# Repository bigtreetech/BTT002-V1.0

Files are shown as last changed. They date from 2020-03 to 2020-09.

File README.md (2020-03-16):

### Note
* The firmware of this motherboard is default Marlin2.0；
* Since the prusa machine is not equipped with endstop switch, to use the endstop switch function, either TMC2130 or TMC2209 must be used.According to the test results, using the TMC2209 driver is more cost-effective. Therefore, it is recommended that the customer use TMC2209 driver；
* If you want to use drivers other than TMC2209 and TMC2130, you need to install endstop switch on the machine；
* Because the board uses a plug drive, the overall height is higher than the original machine housing. According to the motherboard, our company makes a 3D model to adapte the shell. So the customer can printed out the shell and install on the machine for use;
* The firmware of the motherboard is updated by SD card. The client can put the compiled. bin file into the SD card of LCD2004 screen, then repower to update the firmware.
* When using Marlin firmware, you can use the new processing capabilities such as RGB light function, WIFI printing function, TFT touch screen and dual-mode touch  screen.

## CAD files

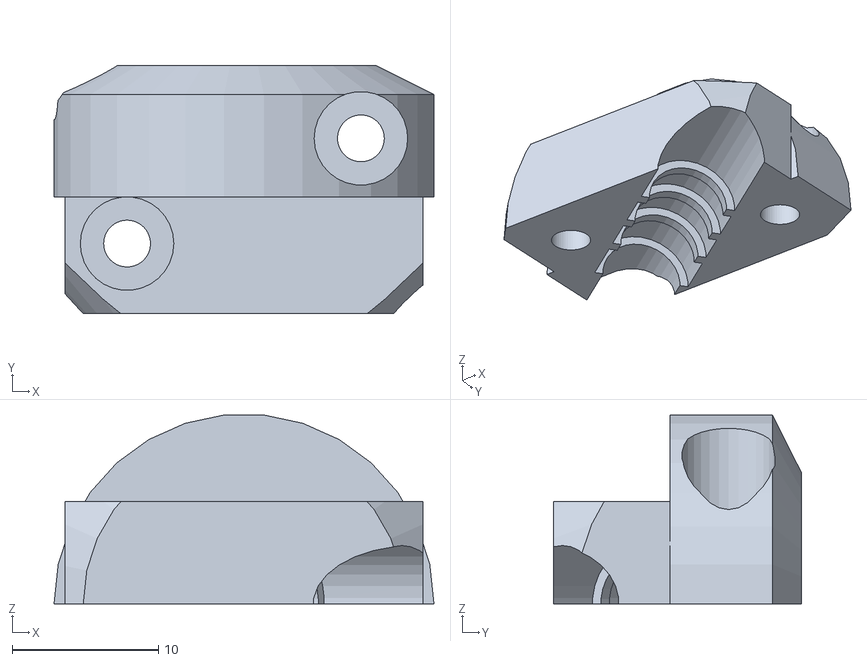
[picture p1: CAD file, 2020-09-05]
3D Mode/Heatbed-cable-clip.stl
26.0 x 17.0 x 12.9

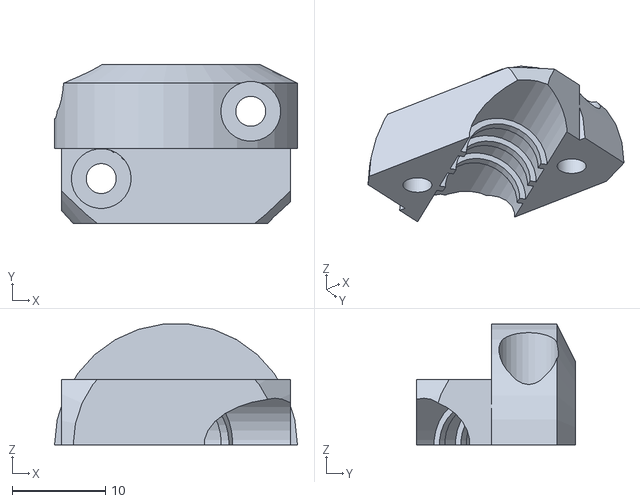
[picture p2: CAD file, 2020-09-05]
3D Mode/Heatbed-cable-clip_for_8mm_sleeve.stl
26.0 x 17.0 x 12.9

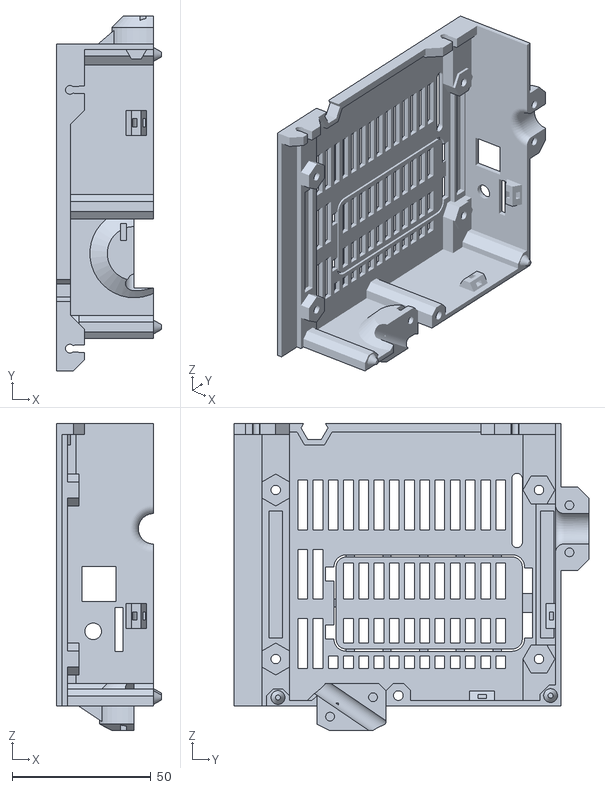
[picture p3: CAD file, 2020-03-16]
3D Mode/prusa i3 主板支架 4015.STL
37.8 x 128.0 x 110.8

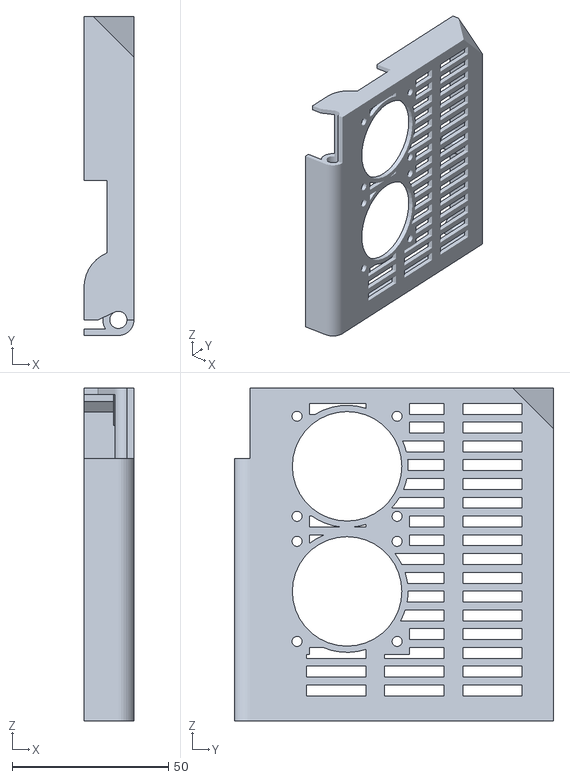
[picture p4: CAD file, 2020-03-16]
3D Mode/prusa i3 主板支架外壳 4015.STL
16.0 x 102.0 x 106.4

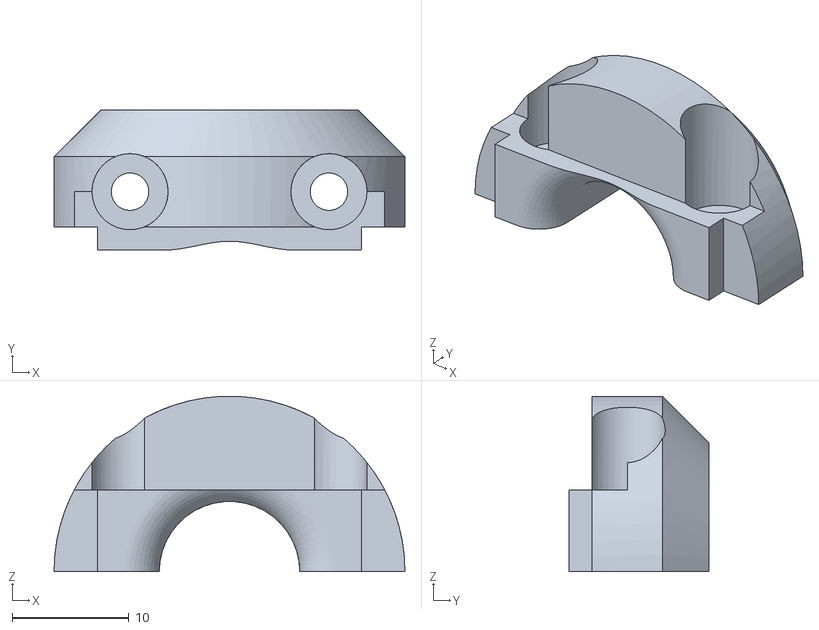
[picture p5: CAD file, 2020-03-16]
3D Mode/线夹-10.STL
30.0 x 12.0 x 15.0

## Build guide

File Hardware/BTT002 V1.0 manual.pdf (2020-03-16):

Shenzhen BIGTREE technology co., LTD.

### BIG TREE TECH

# BIGTREETECH

# BTT002 V1.0

# Manual

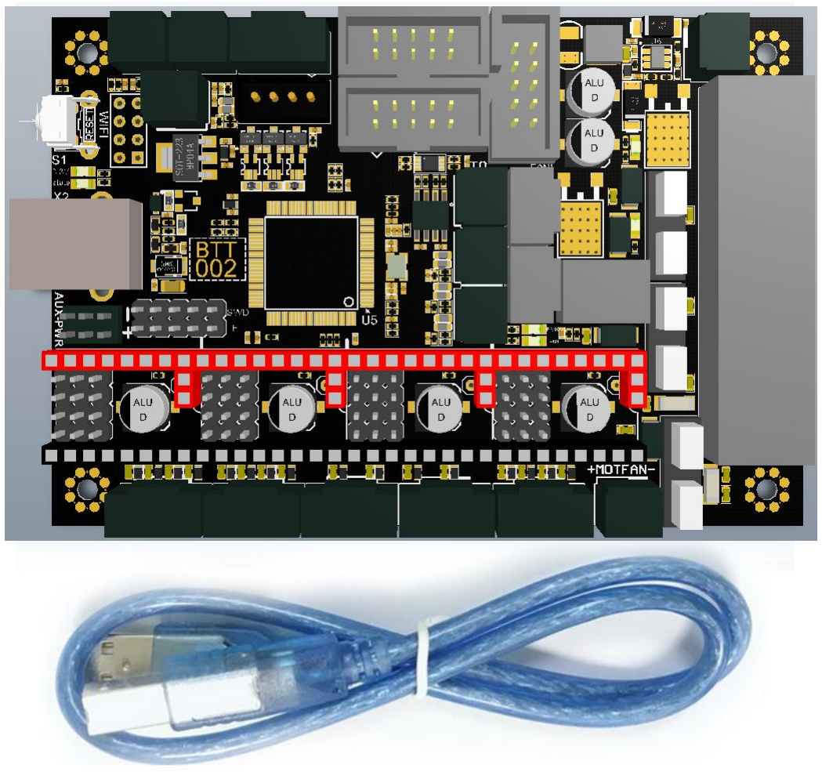
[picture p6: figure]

### BIG TREE TECH

# I. Preface

BigTree Technology Co., Ltd. developed BIGTREETECH BTT002

V1.0 to provide a direct replacement for the Prusa i3 MK3S which has

more options.

Main features

1）The board is controlled by a STMicroelectronics ARM Cortex M4 32-bit STM32F407VGT6 MCU. This chip has a Maximum Clock Frequency of 168 MHZ.
2）use a powerful integrated development environment of Visual Studio Code: support online debugging, which is more helpful for product development and performance optimization, and adopt C language for development with low development difficulty.
3） The firmware is upgraded with a SD card, which is very convenient and efficient!
4）The layout of the PCB is optimized for heat dissipation. 5）Support 24V power input, High voltage input means heated bed current draw can be reduced to 1/4, without power loss.
6） Support BIGTREETECH TFT24 V1.1、TFT28、TFT3.5 V2.0、TFT35 V3.0 and LCD12864/2004；
7）Firmware is adopted to set the driving current to avoid manual adjustment of current resulting in burnt out drive, which is convenient, safe and reliable.
8）Reserve WIFI expansion port, support ESP3D wireless printing; 9）Support TMC2130/5160/5161 SPI mode.
10）Support TMC2208/2209 UART mode.
11）Support RGB LED strips；
12）Support parallel dual Z axis；
13）Reserve 5V and VMOT cooling fans for improving heat dissipation;
14）Automobile fuses are used for easy replacement after blown out；
15）Reserve EXP3 expansion port, including I2C and UART expansion port.

### BIG TREE TECH

Board specifications

Appearance size： 105*71mm
Install size： Perfect replacement of Prusa i3 MK3S motherboard, see file “BTT002 V1.0 SIZE” for details
MCU： ARM Cortex-M4 CPU
Power Input： 12/24V
Logic Voltage： 3.3V
Stepper motors： 5 ways motor ports（including dual-z motors ） Motor drives： XM、 YM、 ZM、 EM
Thermistors： 4 ways: TH0、 TH1、TH2 and onboard NTC100K Display： TFT and EXP1、EXP2 for LCD
Endstops：3 ways: X-MIN、Y-MIN、Z-Probe
Fans：two 5V CNC fans, one 5V fan (always on), one VMOT fan (always on)
Other ports: Nozzle, heat bed, RGB LED strips and WIFI module Default firmware: Marlin 2.0
PC communicating port： USB-B, baudrate 115200
Support file format： G-code
Recommend printing software： Cura、 Simplify3D、 pronterface、 Repetier-host、 Makerware

# II. Onboard LED information

The 3.3V green LED is the power indicator light. The LED is on when the board is powered.
The yellow ‘status’ LED flashes when the firmware is updated, and stops flashing when the update is complete.
The red LED3 is the heated bed status indicator light. It is on when the heated bed is powered and off when the heated bed is not powered.
The red LED2 is the extruder status indicator light. It is on when the extruder is powered and off when the extruder is not powered.
The red LED0 is the FAN0 status indicator light. It is on when The fan is powered and off when the fan is not powered. The red LED1 is the FAN1 status indicator light. It is on when the fan is powered and off when the fan is not powered.

# III. Communication between board and PC

After the board is connected to the computer through the USB cable, the computer will automatically install the needed driver. After the driver installation is completed, the board can be identified for data

### BIG TREE TECH

transmission. If the installation fails, you can download the needed driver from here:
https://github.com/bigtreetech/BIGTREETECH-SKR-MINI-V1.1/tree/master/firmware/mapleDrv-USBdriver (https://github.com/bigtreetech/BIGTREETECH-SKR-MINI-V1.1/tree/master/firmware/mapleDrv-USBdriver)
Download the file named mapleDrv for installation. After the driver installation is completed, open the ”Device Manager” to see the port to which the board is connected. If you see the same as in the picture below, then the board is successfully connected.

The computer shows different COM port name with different drivers.

# IV. Board ports

Pin diagram

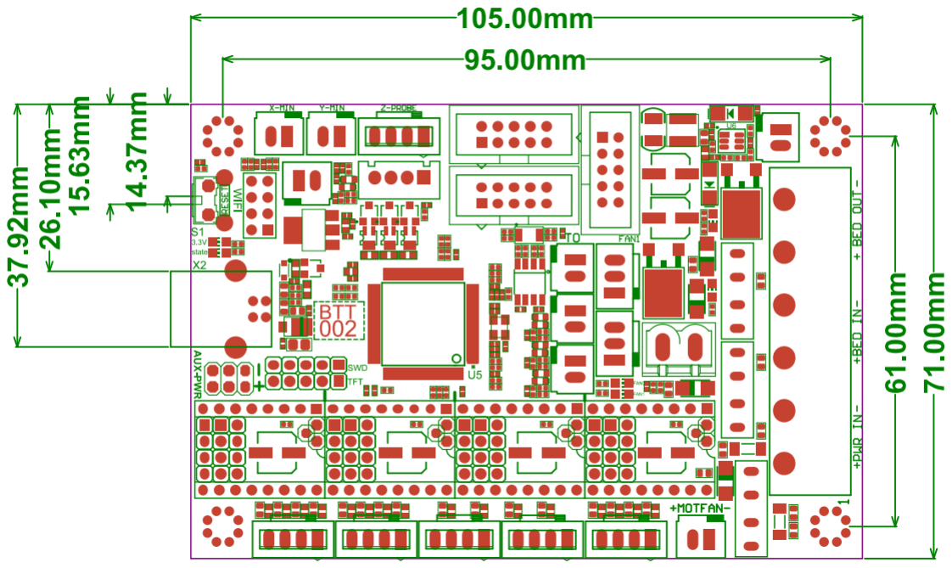
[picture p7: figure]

### BIG TREE TECH

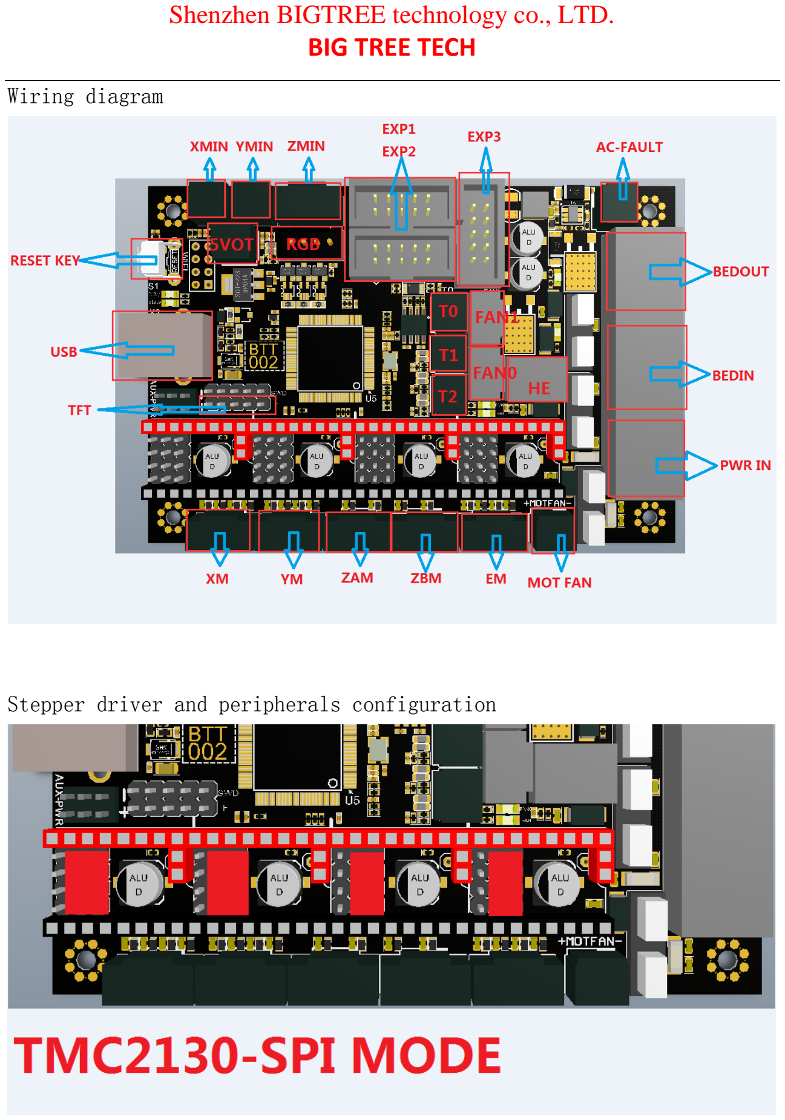
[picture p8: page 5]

Wiring diagram

Stepper driver and peripherals configuration

### BIG TREE TECH

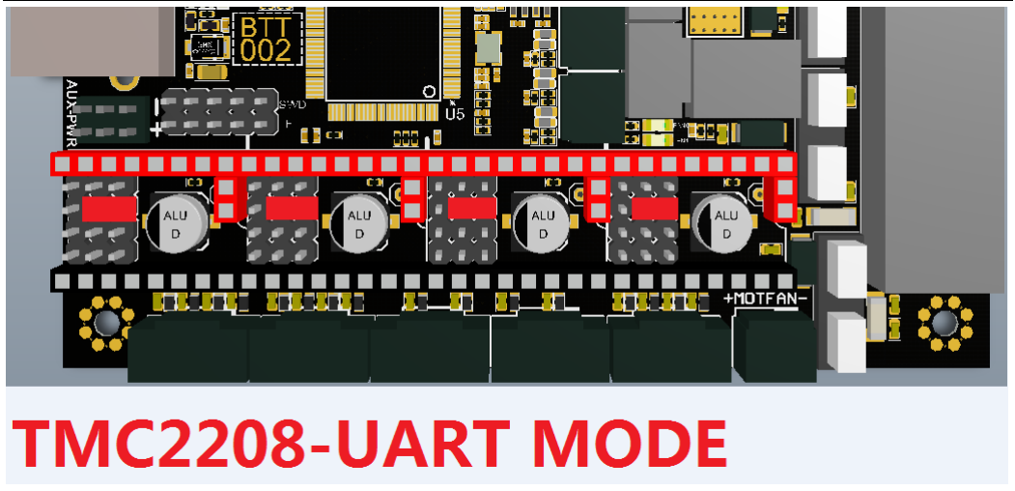
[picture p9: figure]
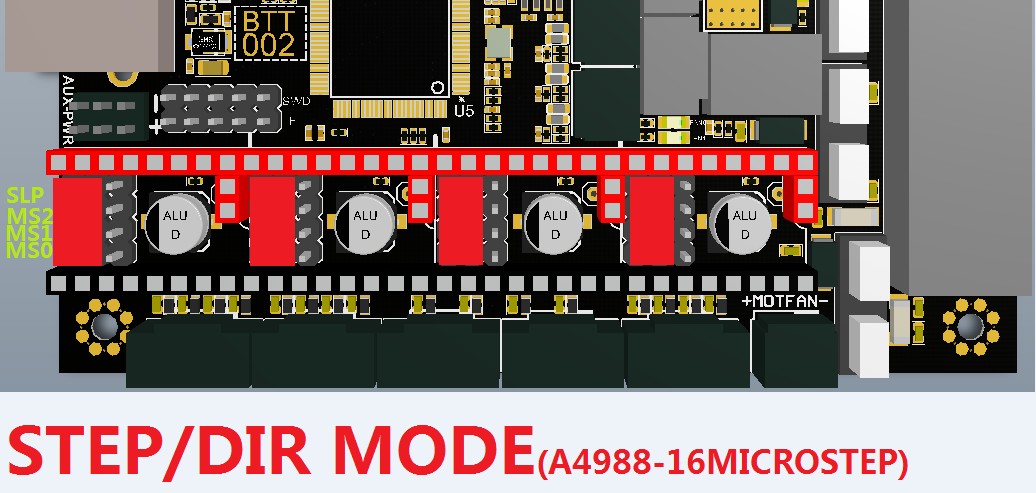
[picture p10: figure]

# V. Firmware

By default there will be a Marlin 2.0 firmware installed on the board, which is optimized for i3 machine. It is also possible to make changes to the firmware.

You can find the needed firmware files on our Github page: https://github.com/bigtreetech
You can also get the firmware from customer service or technical assistant.

Marlin2.0 firmware update method
After downloading the files, use Visual Studio Code to open the project for compilation. Customize the firmware and compile it. Check for errors. If there are no errors, find the firmware.bin file. Copy it to the SD card and plug the SD card in the board. Reboot the board, wait for about 10 seconds before doing anything else with the board.

### BIG TREE TECH

Note: The bootloader in the main chip will be erased if user flash firmware by USB cable, the board also no longer upgrade the firmware by SD card. This way for flashing firmware also needs to change many configurations, it is not recommended that users update the firmware by USB cable!
3. Please refer to BTT002 V1.0 PIN file for motherboard firmware DIY.

# VI. Notes

1.File name cannot be changed, firmware.bin must be lowercase!

2.Ensure that all wires, jumper and drivers are correctly

plugged in before power-on.

3.BTT002 V1.0 is a motherboard designed specifically for the

Pruse i3 MK3S printer. If you want to use another machine,

please refer to the corresponding electrical parameters of

Ender3 (such as heated bed power, extruder cartridge power,

etc.). The electrical parameters of other machines should

never exceed the electrical parameters of the Prusa i3 MK3S.

Our company will not compensate for any losses caused.

4.Motor driver mode and microsteps must be consistent with

the firmware, otherwise it is easy to cause the motor does

not work;

5.The default firmware is Marlin 2.0 (capable of 3D model

printing and functions in Marlin), not the original firmware

of Prusa i3 MK3S printer. When you want to use the special

functions of Prusa i3 MK3S printer,you need DIY the firmware.

### BIG TREE TECH

If you encounter other problems while using, please contact

us, we will answer you scrupulous; if you have any good

comments or suggestions for our products, pls feel free to

inform us, we will carefully consider your comments or

suggestions, thank you for choosing BIGTREETECH products,

thank you!

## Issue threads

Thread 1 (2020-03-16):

Missing schematics

Lino77, 2020-03-16:
Could you please upload the schematics for the BTT002-V1.0  Board.

Thanks in advance

thisiskeithb, 2020-06-09:
[They've been added](https://github.com/bigtreetech/BTT002-V1.0/blob/7c1048484338716e2f823528319dfaf37559c367/Hardware/BTT002%20V1.0SCH.pdf).

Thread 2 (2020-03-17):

missing schematics

mstewart1987, 2020-03-17:
missing the cover plate for the hotbed cables.  only supplied cover plate for extruder.

thisiskeithb, 2020-06-09:
I sent a note to Biqu/BigTreeTech about this missing heatbed cable clip since Prusa's doesn't fit in that spot.

In the meantime, Juan Puchol made a pretty awesome [Universal BTT002 Box](https://www.thingiverse.com/thing:4231370). Be sure to read the readme for more info, including links to the other parts of the box.

Your title mentions missing schematics and [those have been uploaded](https://github.com/bigtreetech/BTT002-V1.0/blob/7c1048484338716e2f823528319dfaf37559c367/Hardware/BTT002%20V1.0SCH.pdf).

3d-gussner, 2020-06-11:
@thisiskeithb Yes and no, the schematics are old and don't have the new STM32 chip with 1024
Also i cannot find the connection to the diag and index pin in there.

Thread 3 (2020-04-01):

firmware flashing over sd with TFT35 V3.0 does not work

Lino77, 2020-04-01:
firmware flashing over sd with TFT35 V3.0 does not work. how can you get the firmware on the board. without changing the display every time

michaelshulichenko, 2020-05-15:
in my case flashing works only with RepRap Discount Smart Controller (2004)
it does not work with Full Graphic Smart Controller (12864) and BTT TFT 35 v2.0
i am flashing it with stlink (be careful to not erase bootloader, marlin code starts from 0x08008000 )

thisiskeithb, 2020-05-16:
The major pitfall is that once you update the firmware to use a different LCD than a stock MK3S 2004 character style (`REPRAP_DISCOUNT_SMART_CONTROLLER`), you're stuck using an ST-Link for future updates.

chzj333, 2020-05-18:
> in my case flashing works only with RepRap Discount Smart Controller (2004)
> it does not work with Full Graphic Smart Controller (12864) and BTT TFT 35 v2.0
> i am flashing it with stlink (be careful to not erase bootloader, marlin code starts from 0x08008000 )

I removed the motherboard from the machine, only used USB power, and connected 12864, then it was updated, maybe you can try it.

thisiskeithb, 2020-06-09:
I spoke with an engineer at Biqu/BigTreeTech, they provided an answer as to why flashing from a TFT doesn't work:

> Our engineers said the LCD mode in TFT35/E3 V3.0 is a LCD simulator, the EXP1 and EXP2 cable are connected to MCU on the display, not connected to SD slot. So the BTT002 cannot flash firmware by SD slot on TFT35 display.

You'll have to use a traditional full graphic or text LCD to update the firmware on a BTT002.

I suggested they add an onboard SD card reader, similar to their other boards, so users won't run into this issues when using TFTs.

iShavgula, 2020-08-14:
Hello,

I'm totally new to this and I've got:
- BTT002
- TFT35 v3.0

Nothing else: other displays, ST-link, etc..

The display turns on, shows me two choices to proceed: `Marlin mode` and `Touch mode` but I can not click on any of them.

I'm having trouble updating the board firmware as mentioned in this issue. Are there any updates on this ? If I have to buy something additional(ST-Link for example) what would be the best choice ?

Thanks

iShavgula, 2020-08-15:
Hello again,

I got the ST-Link and I'm using OS X. Could you please tell me to which address I should flash the firmware?
Thanks

iShavgula, 2020-08-15:
Hello,

I got the ST-Link, flashed the new firmware but I still got the same results.
Here the modifications I applied to the BTT002 Marlin configuration:
- uncomment `REPRAP_DISCOUNT_FULL_GRAPHIC_SMART_CONTROLLER`
- set `LCD_INFO_SCREEN_STYLE` to 0 instead of 1

iShavgula, 2020-08-15:
I connected only the serial port and the now the display works, but only in touch mode.

Closed 2021-01-04.

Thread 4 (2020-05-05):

Calibration Issue

bpvarsity, 2020-05-05:
Installed on a stock MK3S and when I do Z Home or bed level the extruder and nozzle dive into my bed. What do I need to change?

thisiskeithb, 2020-05-06:
In case someone else comes across this issue: Don’t forget to remove the diag pins on Z and E drivers or this will happen 🙂

Afterschnitzel, 2020-12-21:
Thanks, you saved mi life :-D

Closed 2020-05-06.

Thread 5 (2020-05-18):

Flashing BTT002-V1.0 doesn't write CUR

ogland, 2020-05-18:
As the title reads, it seems to flash fine but the BIN file persists. This is using different 128 mb cards from BTT and both with 2004 LCD and 12864 LCD.

Same behaviour if powered through USB or externally.

Also as a sidenote, one of the motors doesn't move properly. I'm not sure if that's related to some kind of incomplete write of firmware or if it's a physical error. I moved drivers and motors around and it's linked to the specific port/pins.

thisiskeithb, 2020-06-09:
> As the title reads, it seems to flash fine but the BIN file persists. This is using different 128 mb cards from BTT and both with 2004 LCD and 12864 LCD.

Does a .cur file exist on the SD card? I found that I had to delete the .cur file after flashing since the bootloader doesn't overwrite it. I also ran into this issue on some other BigTreeTech boards.

Afterschnitzel, 2020-12-22:
I can confirm it. FW will flash, but firmware.bin is not renamed as FIRMWARE.CUR

ebraiman, 2021-01-01:
@Afterschnitzel May I ask the process of loading the firmware on the BTT002?  Are you loading via a SD card through a LCD or TFT?

Afterschnitzel, 2021-01-02:
I do'nt use TFT, because I am running my printer on Klipper. I made flashing proccess via SD card through Fysetc 12864 Mini Neopixel.

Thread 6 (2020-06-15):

BTT002-V1.0-TMC connection error

ProgChaos, 2020-06-15:
the 2209 v.1.2 stepper drivers from Bigtreech, gives me
the tmc connection error on Marlin 2.0.5. (factory firmware.bin)

Recv: X 0x00:00:00:00 Bad response!
Testing X connection... Error: All LOW
Y Z E0 are all ok.

Switched the drivers, same result, jumper are all set to UART-mode.
(see manual)

Thanks :)

gcastrataro, 2021-08-14:
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

Can anyone let me know how to resolve this issue.  I am experiencing the exact same problem.

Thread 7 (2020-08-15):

TFT35 v3.0 No printer attached!

iShavgula, 2020-08-15:
Hello,

I'm trying to connect BTT TFT35 v3.0 to the BTT002 board and I'm getting this error: `No printer attached`.

Here are the modifications I applied to the original BTT002 Marlin setup:
- uncomment REPRAP_DISCOUNT_FULL_GRAPHIC_SMART_CONTROLLER
- set LCD_INFO_SCREEN_STYLE to 0 instead of 1

I tried to play with these settings, but in vain:
- BAUDRATE 115200
- SERIAL_PORT 3
- SERIAL_PORT_2 -1

What am I missing?

Thanks

iShavgula, 2020-08-16:
I plugged in only the TFT cable without reset pin and the printer got detected.

I'd not say the issue is resolved as I still can't use the marlin mode.

DoNotGood, 2020-10-06:
Hello iShavgula,
today I got my tft35 (I also have Prusa MK3s with BTT002 V1.0) and I have exactly the same problems with display!

Do you have found a solution, which works well in Marlin- and in TFT-mode?

I could not choose Marlin-mode.

I connected EXP1+2 and TFT, do I also have to connect +5V and GND (Power Supply)?

Both Boards are made by BigTreeTech, so it must have been tested before, didn't it?

iShavgula, 2020-10-06:
Hello @DoNotGood,

I kind of found a solution: I replaced it with a LCD2004 display and I'm happy with it.

Sorry, but here is no hope(imho) for BTT002 + TFT35.

Anyways, I'm using PrusaSlicer + OctoPrint and rarely have to use the display. I may as well test the BTT wifi module in the future, which is a much cheaper alternative to OctroPrint.

Szarp78, 2020-10-15:
Hello @iShavgula , @DoNotGood

To use Marlin mode, you must rotate the ribbon cables 180 degrees, but only on one side.

I have BTT002 + TFT43 and it works, but still, to change the firmware, you need to connect the old LCD2004 display.

DoNotGood, 2020-10-31:
Good morning @iShavgula,

I've tried your suggestion (turn around the cables about 180 °), and now the Marlin mode works, thx, but in Touch mode I have still no connection to the printer and I can't use the touch screen, it isn't reacting, it does not work, but when I stay with the finger on the screen, it switches to the menu, where I can choose Marlin or Touch mode, so it means the touch function of the display can't be totally dodgy!

iShavgula, 2020-10-31:
Good morning,

Even with the LCD2004 I had to rotate the cables so that is board related, if I remember correctly that is mentioned in the manual pdf under hardware directory. But for me the only way to make the TFT work was without the reset pin (you need to connect only 4 cables instead of 5). Did you try that as well?
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

DoNotGood, 2020-11-01:
Hi,

I've tried it (without RST-PIN), still it does not work, no connection no touch function, just Marlin mode.

gafillll, 2021-04-04:
switch exp1 exp2 180 and cut the nutch

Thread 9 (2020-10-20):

MMU2S Unit - connection problem

Szarp78, 2020-10-20:
Hello
I have a problem connecting the MMU2S module, if anyone knows under which pins I need to connect and how to
and how to properly configure a Marlin.

Closed 2020-11-25.

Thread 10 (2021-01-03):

sd crashing

dullenrrc, 2021-01-03:
i'm having some trouble with the board.

If i have an sd card inserted(lcd2004) while either resetting or powering on the board it crashes.
The printer functions ok when i insert the card after powering up.

this issue makes it quite difficult for me to update my firmware.

i have tried 3 different displays and a lot different sd-cards.

any ideas?

Thanks in advance!

Lino77, 2021-01-04:
I have it too. i solved the problem by using shorter cables to exp1 and exp2. these are max 20 cm long me the 60 cm long is not possible. I have a separate lcd2004 that I only swap for the bottle. there is already a fix or workout for it

stefanomn, 2021-03-28:
in my case an SD card prevents the printer from turning on.
and 99% of the time "with other SD card"
it is really impossible to do a firmware update even using multiple displays
I don't have the possibility to cut the flat cables to do other tests ... it would have been better to stay away from this product and take a skr 1.3 / 1.4 with the adapter cables ... now I would like a refund from the manufacturer ... hopefully

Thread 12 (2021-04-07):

flahing

milicigoran, 2021-04-07:
I read the other threads but didn't find an answer. So i have the Fystec nPrusa mk3s full bear and that comes with a scree that's not the 2004. It worked when the board got here but with senseless homing my hot end kept crashing into the bed. so i wanted to flash marlin firmware where it would make the z axis work as well. I ended up flashing the firmware with stlink. Everything seemed to go well but now i have no picture just 2 lines of blocks with the new firmware i flashed to use the Full graphics, and even when i flash back the bin file from the bigtreetech github I cant see anything on the screen and serial terminal stopped working so i cant conect to it anymore. Any ideas how to get it back to the way it came from btt or what to flash to make it work?

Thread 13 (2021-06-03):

incorrectly labelled expansion pins

craiglink, 2021-06-03:
The pins on EXP1 are incorrectly labeled on the BTT002 V1.0-PIN diagram.  Specifically PE8 and PE9 should be swapped.

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

Those 2 pins map to LCD-EN and LCD-RS as shown in the schematic
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

From the MCU page of the schematic.  LCD-RS maps to PE8 and LCD-EN maps to PE9 indicating they are mislabeled in the PIN diagram

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

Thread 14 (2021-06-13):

TFT43 V3.0 black screen

Thijsvanzwam, 2021-06-13:
For some reason my TFT43 V3.0 just stopped working. No response or anything when touching the screen.
I reflashed the firmware that worked before and now it does nothing. Black screen, no light up button, no beeps. just a black screen and only a little red led on the backside that is on.
I have no way of reinstalling the firmware as it does nothing when inserting the SD card.
Anyone any idea what to do now?

oh... i see I placed this issue in the wrong section. closing it and reopening at the right place...

Closed 2021-06-13.

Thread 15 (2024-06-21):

compatible with oficial prusa firmware?

sl1pkn07, 2024-06-21:
Hi

how luch difficult is make this board compatible with oficial prusa firmware?

greetings

3d-gussner, 2024-06-25:
@sl1pkn07 This is a 32-bit board and you can't use the 8-bit PrusaFirmware. I have seen Marlin 2.x configurations for this board.

sl1pkn07, 2024-06-25:
hi

im not talk about use the AVR arduino framework (8-bits) in this board. im talk about modify the prusa firmware for use with the STM arduino framework (32-bits)

greetings

3d-gussner, 2024-06-25:
@sl1pkn07 I don't think that is possible as the Prusa-Firmware is tailored for the Prusa MK3/S/+, MK2.5/S and diverted long long time ago from Marlin 1.x
If you want to use this board best chances are is to use Marlin 2.x and use that as vanilla Marlin 2.x can run on different hardware/electronics.

sl1pkn07, 2024-06-25:
ok. tnx

3d-gussner, 2024-06-25:
Glad to help, even it is not the answer you wished for

Closed 2024-06-25.

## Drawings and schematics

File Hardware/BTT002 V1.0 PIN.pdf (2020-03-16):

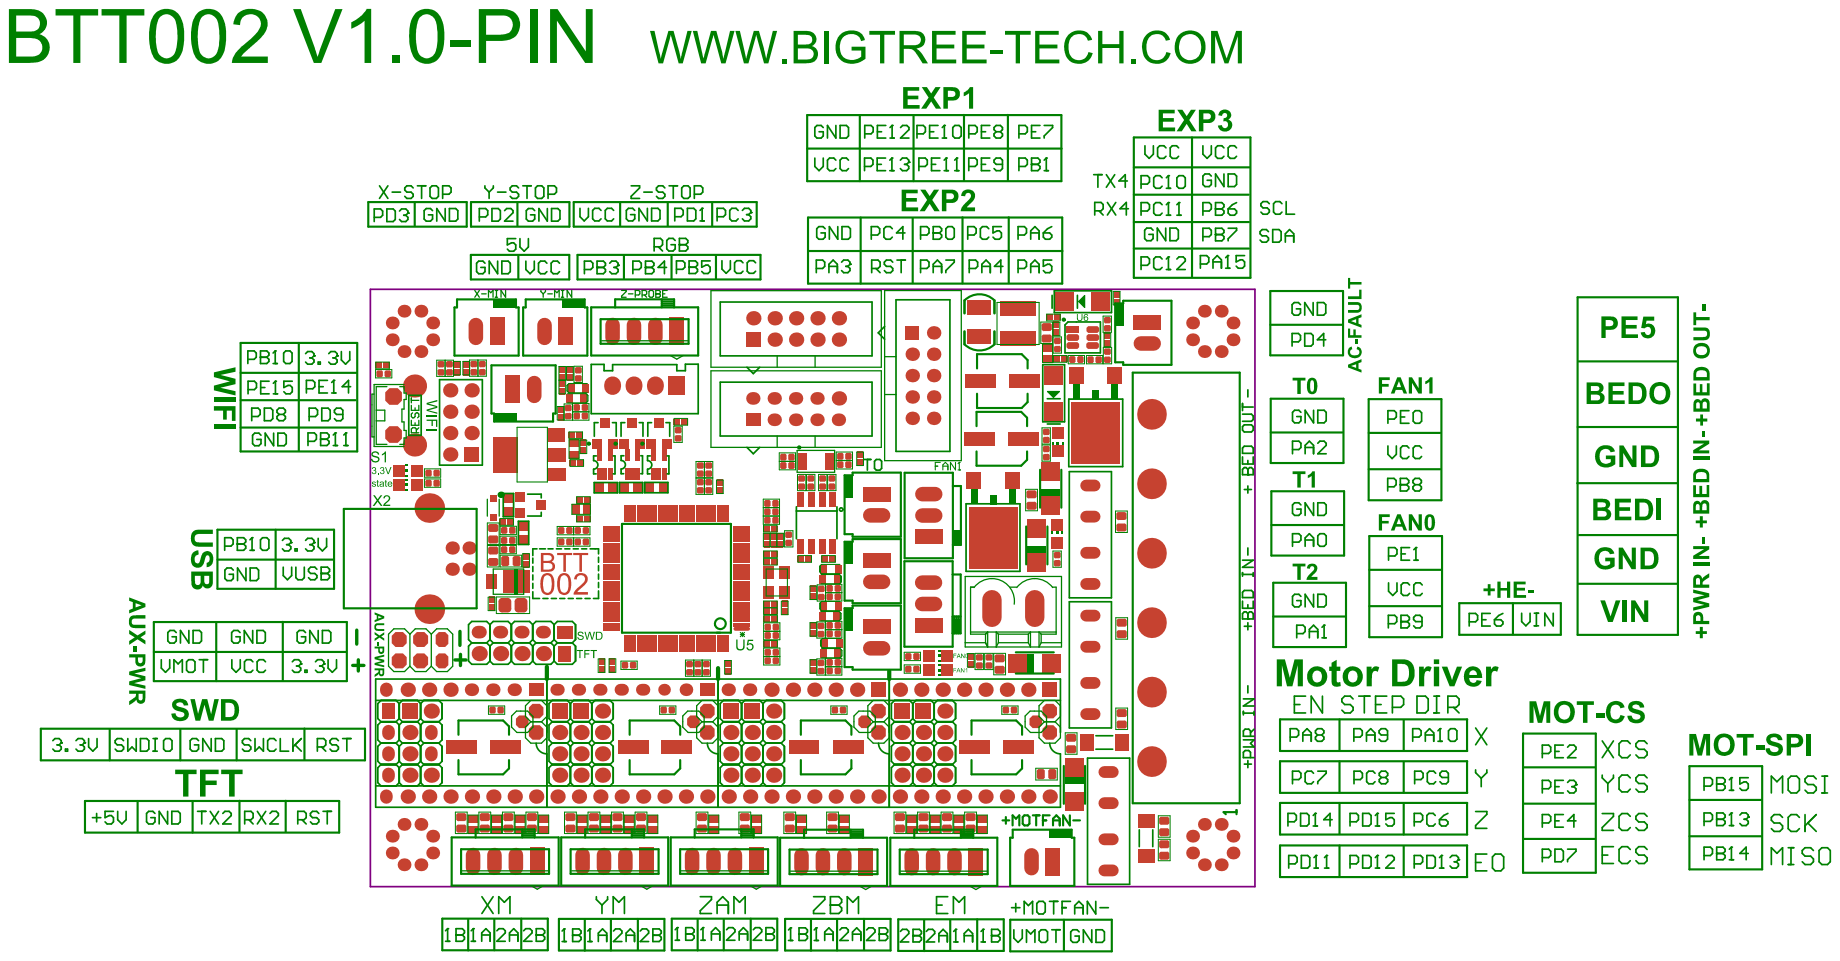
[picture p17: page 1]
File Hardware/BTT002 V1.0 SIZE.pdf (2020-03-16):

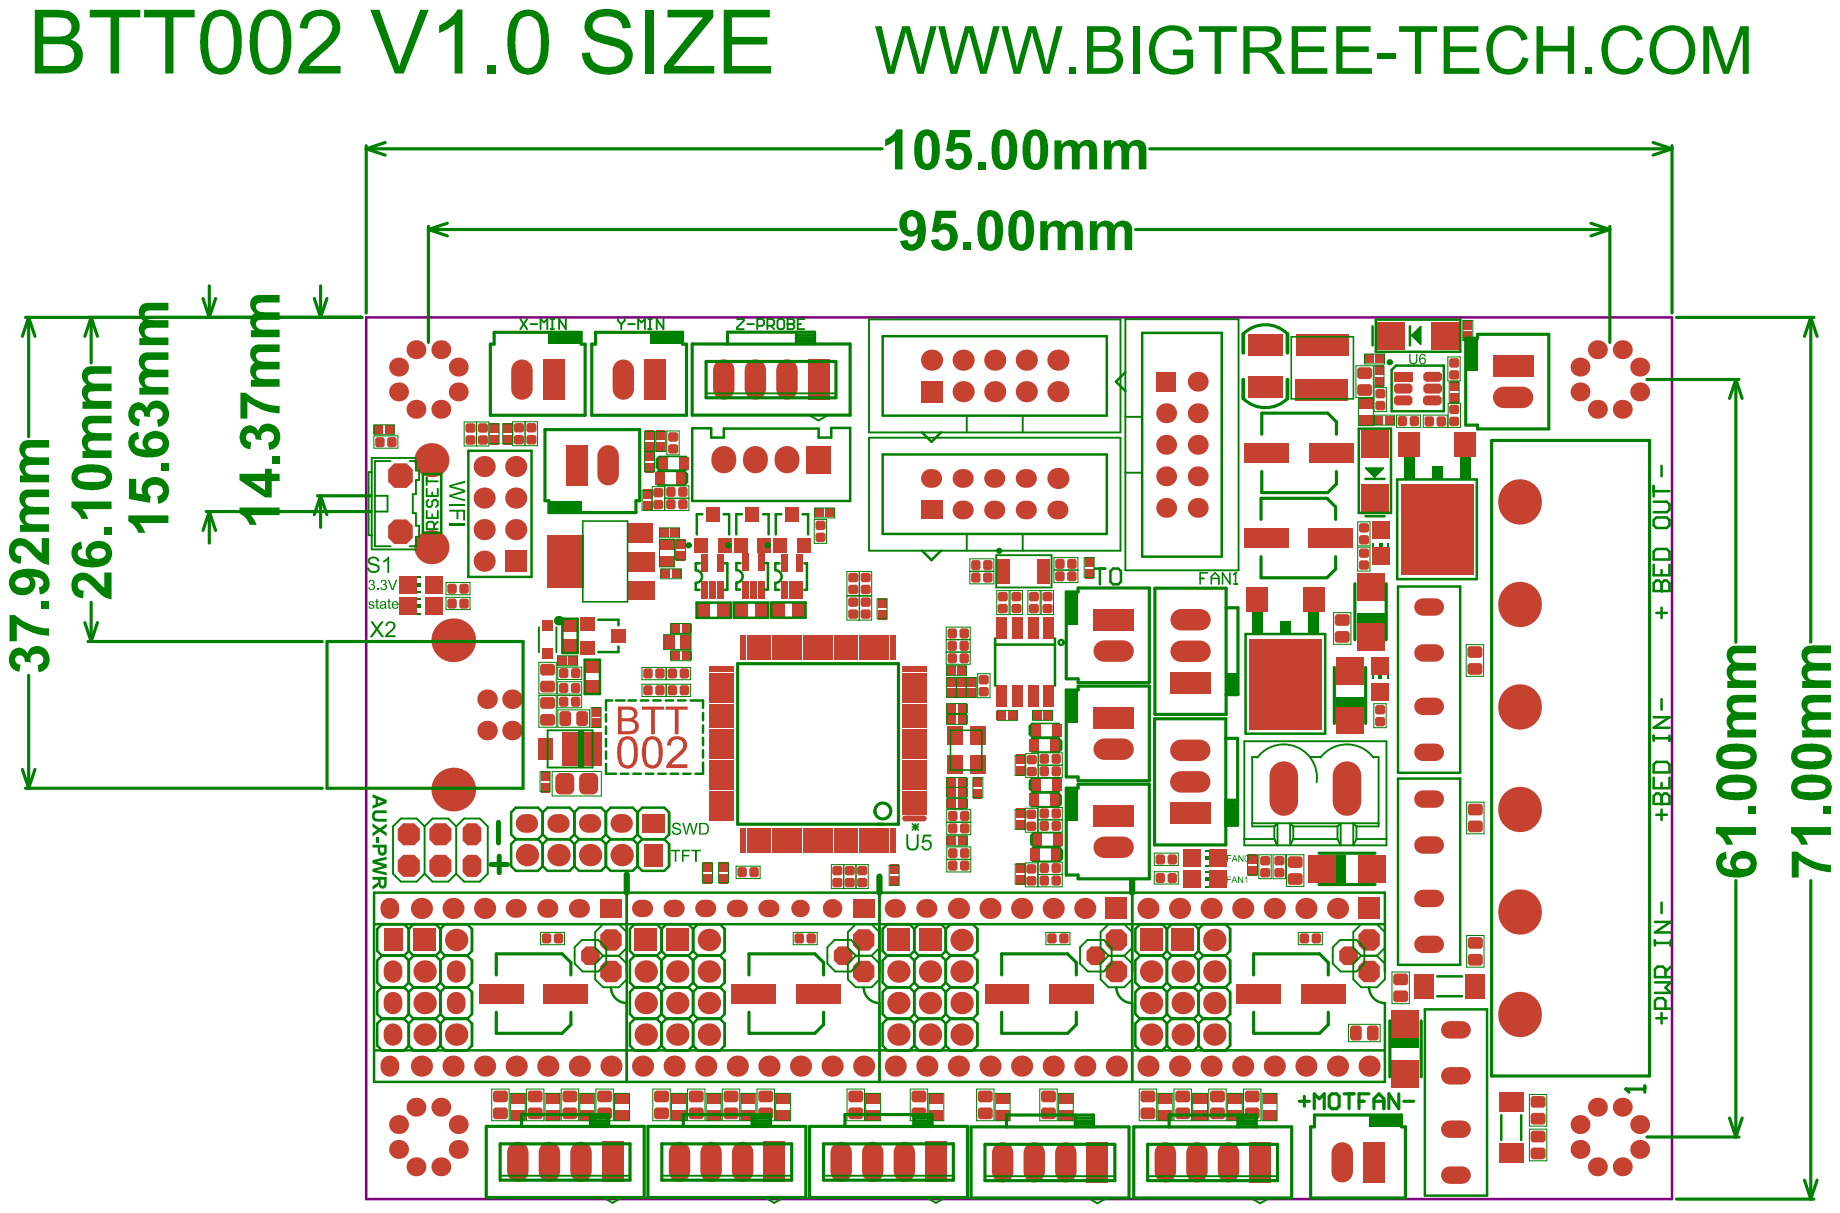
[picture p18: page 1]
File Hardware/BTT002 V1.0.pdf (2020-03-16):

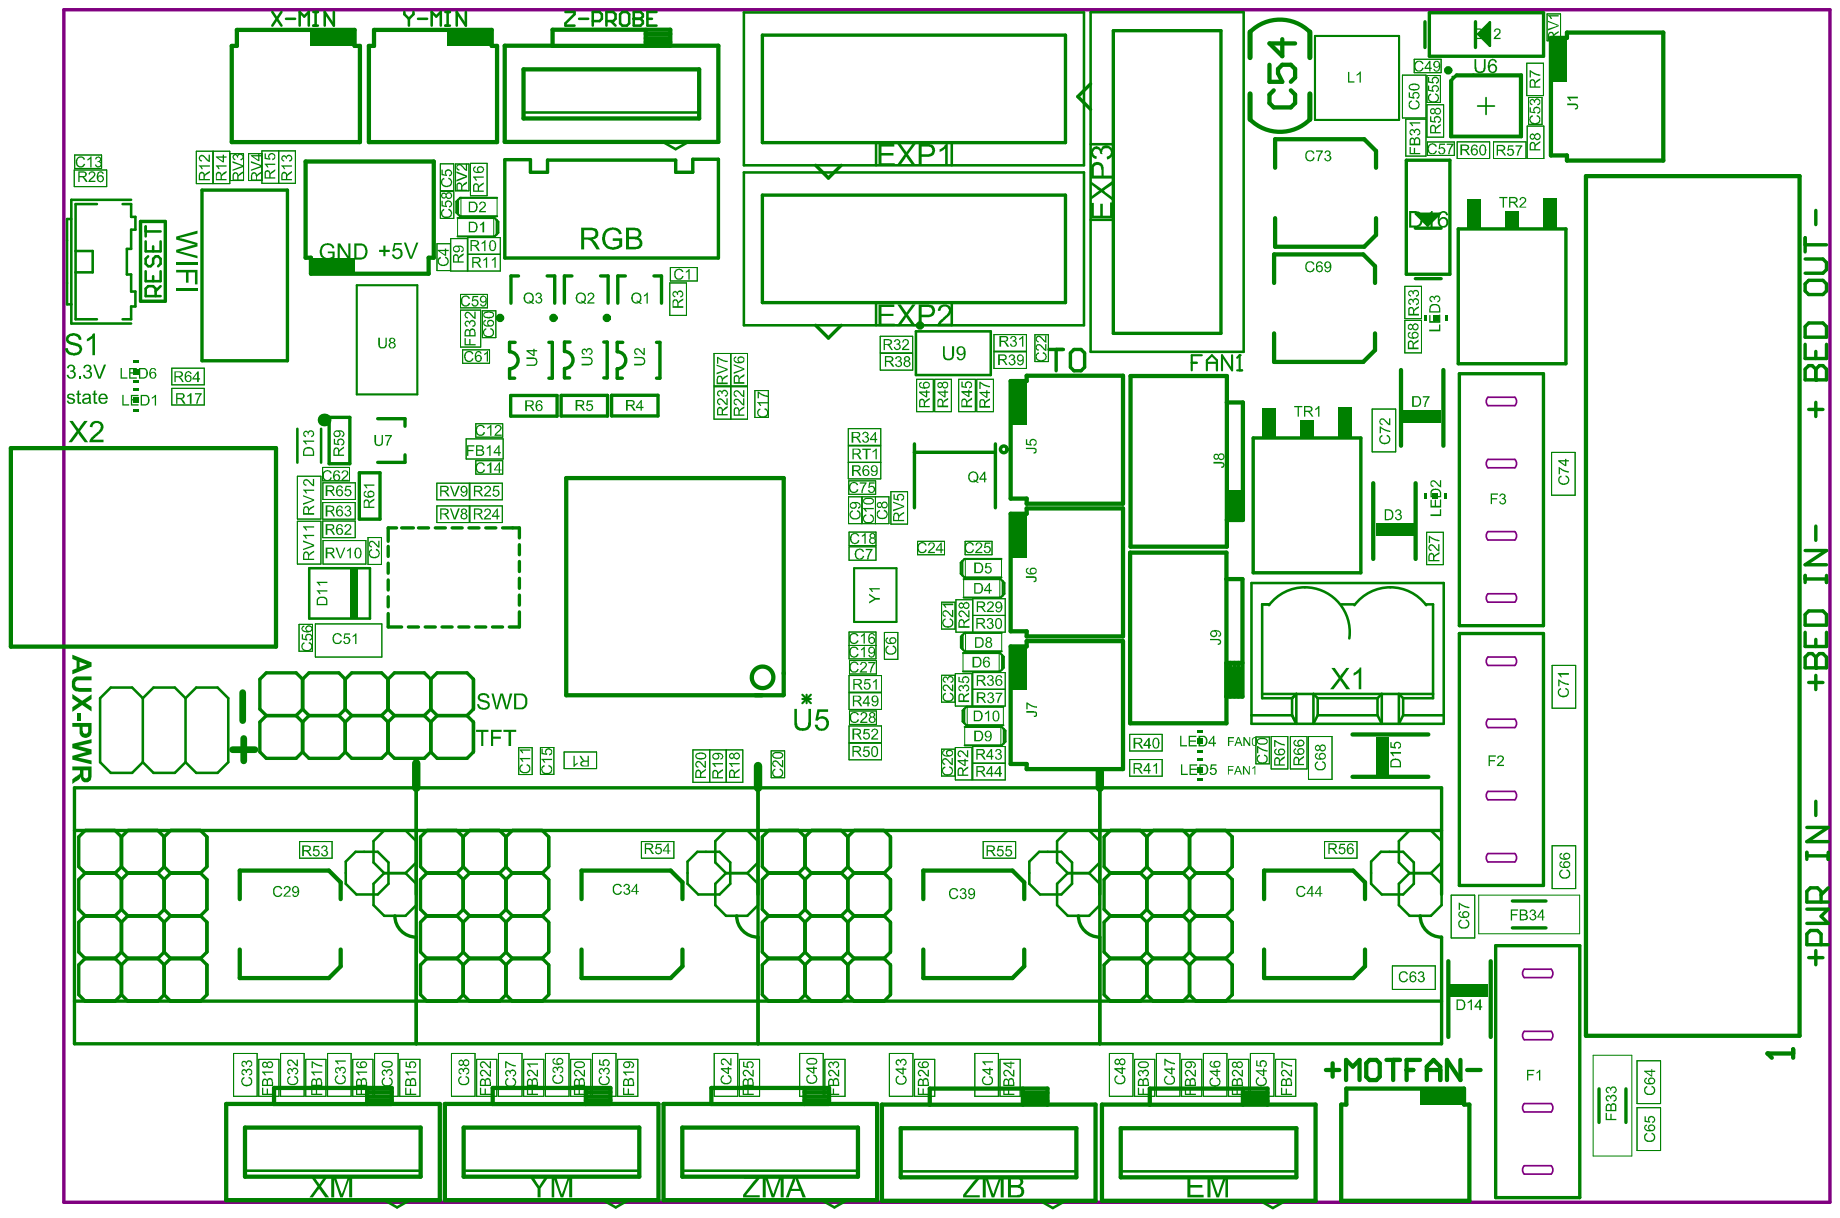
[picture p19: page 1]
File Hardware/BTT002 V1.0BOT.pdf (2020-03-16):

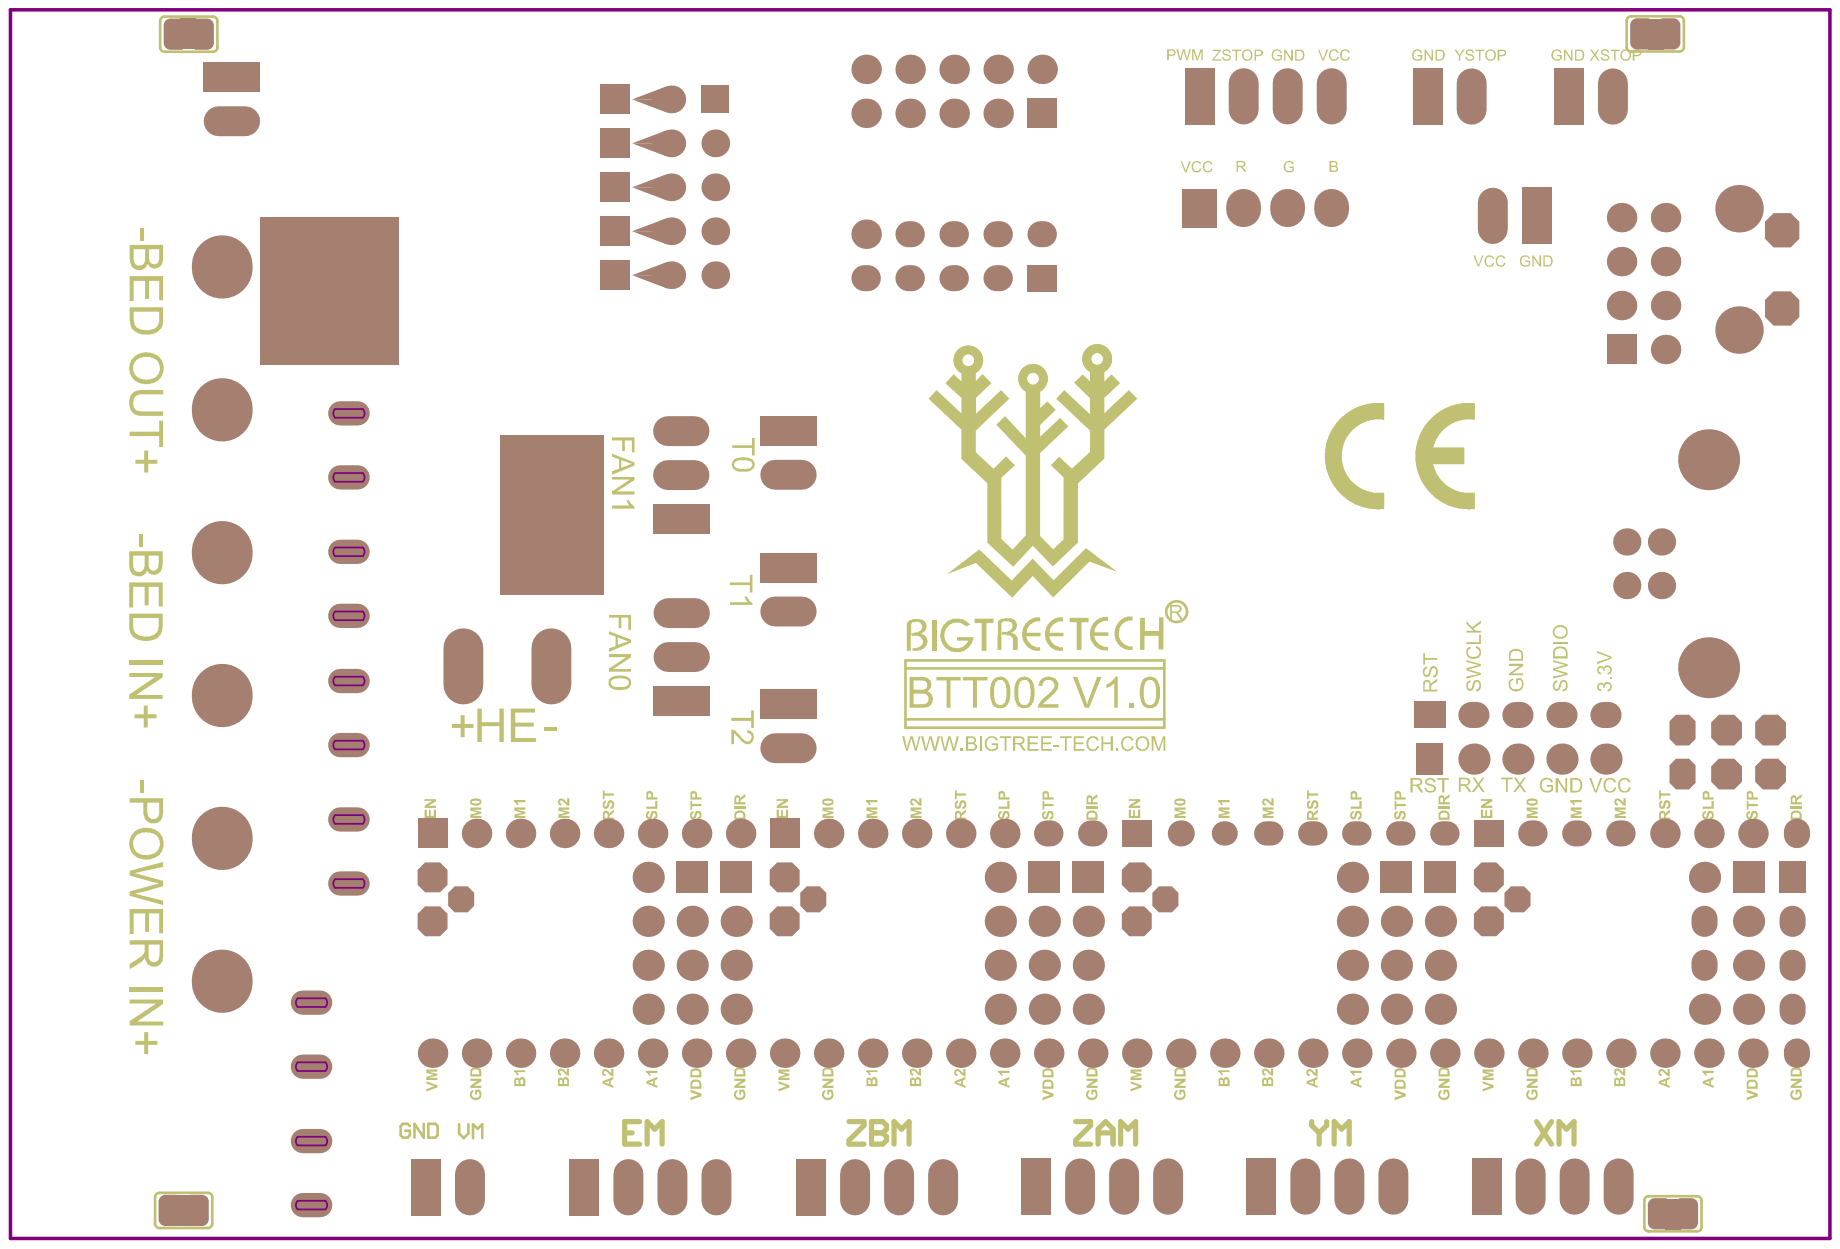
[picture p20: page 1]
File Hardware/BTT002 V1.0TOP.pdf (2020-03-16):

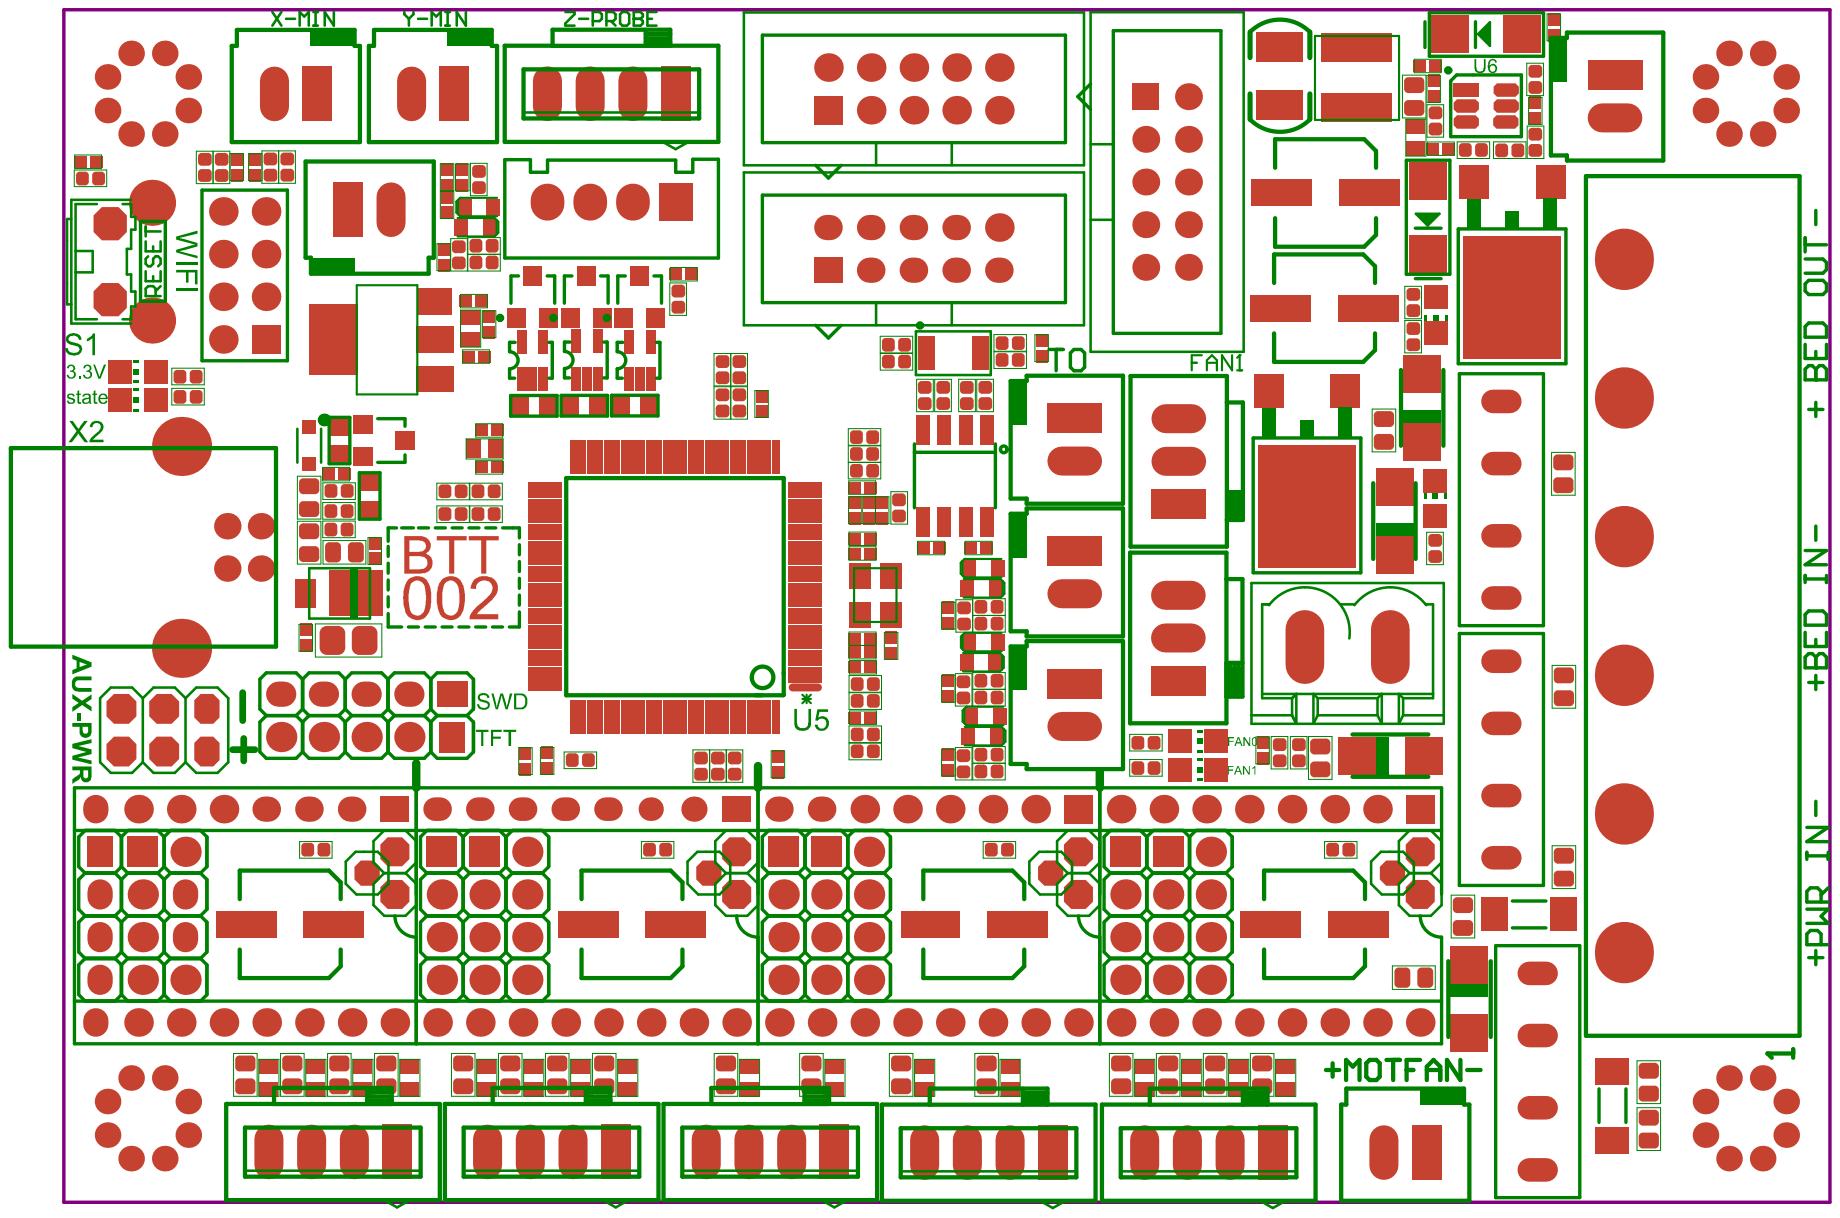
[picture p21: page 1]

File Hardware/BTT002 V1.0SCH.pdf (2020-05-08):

D | D
C | C
B | B
A | A

## Title

Size | Number | Revision

A4

Date: | 2019/12/30 | Sheet of
File: | H:\桌面备份\..\SKR-Einsy-V1.1.SchDoc Drawn By:

## POWER POWER

## ENDSTOP ENDSTOP

## MOS MOS

## DISPLAY DISPLAY

## MOTOR MOTOR

## MCU MCU

A | A
VMOT | VCC

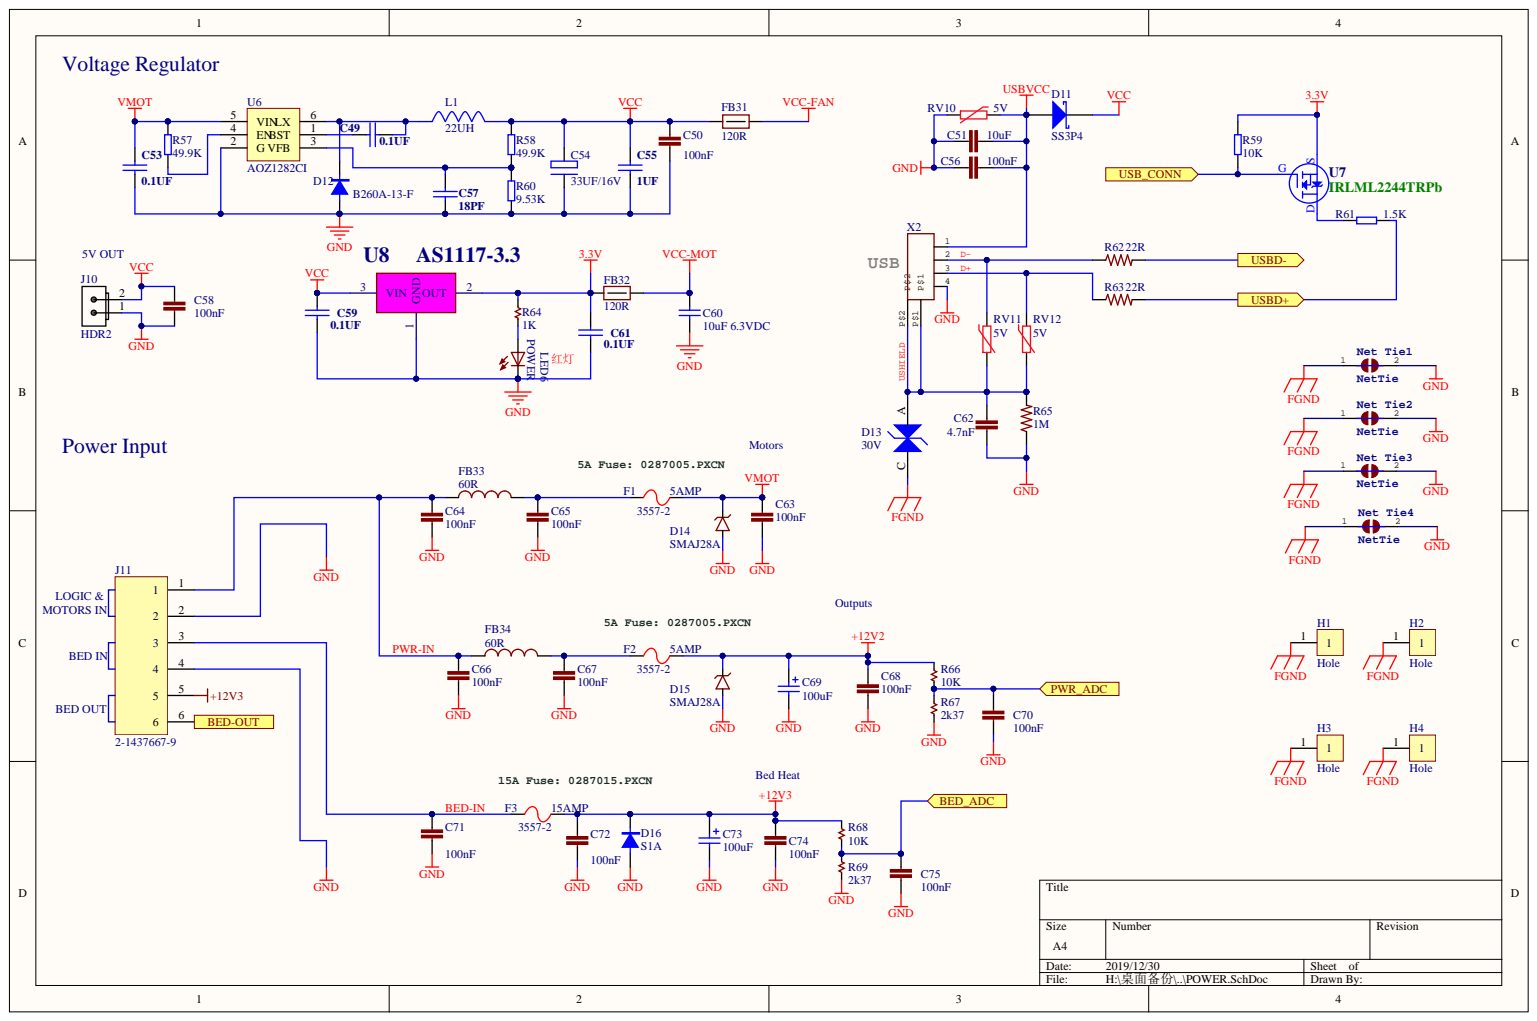
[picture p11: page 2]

11

22

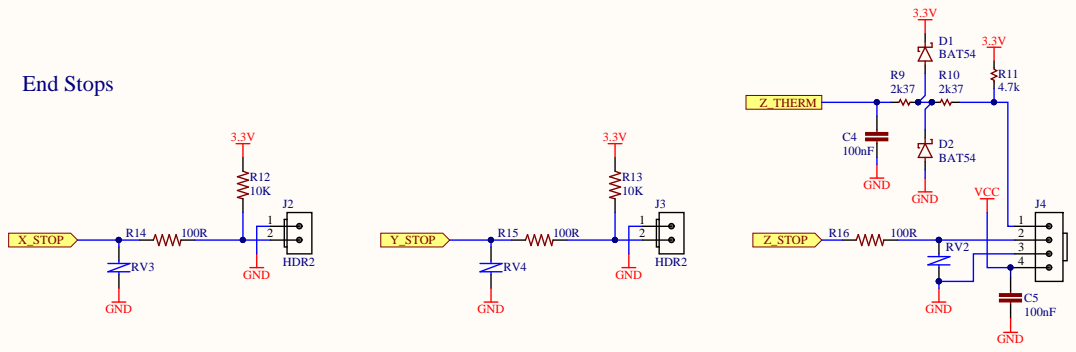
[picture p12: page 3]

A | A

## LED2

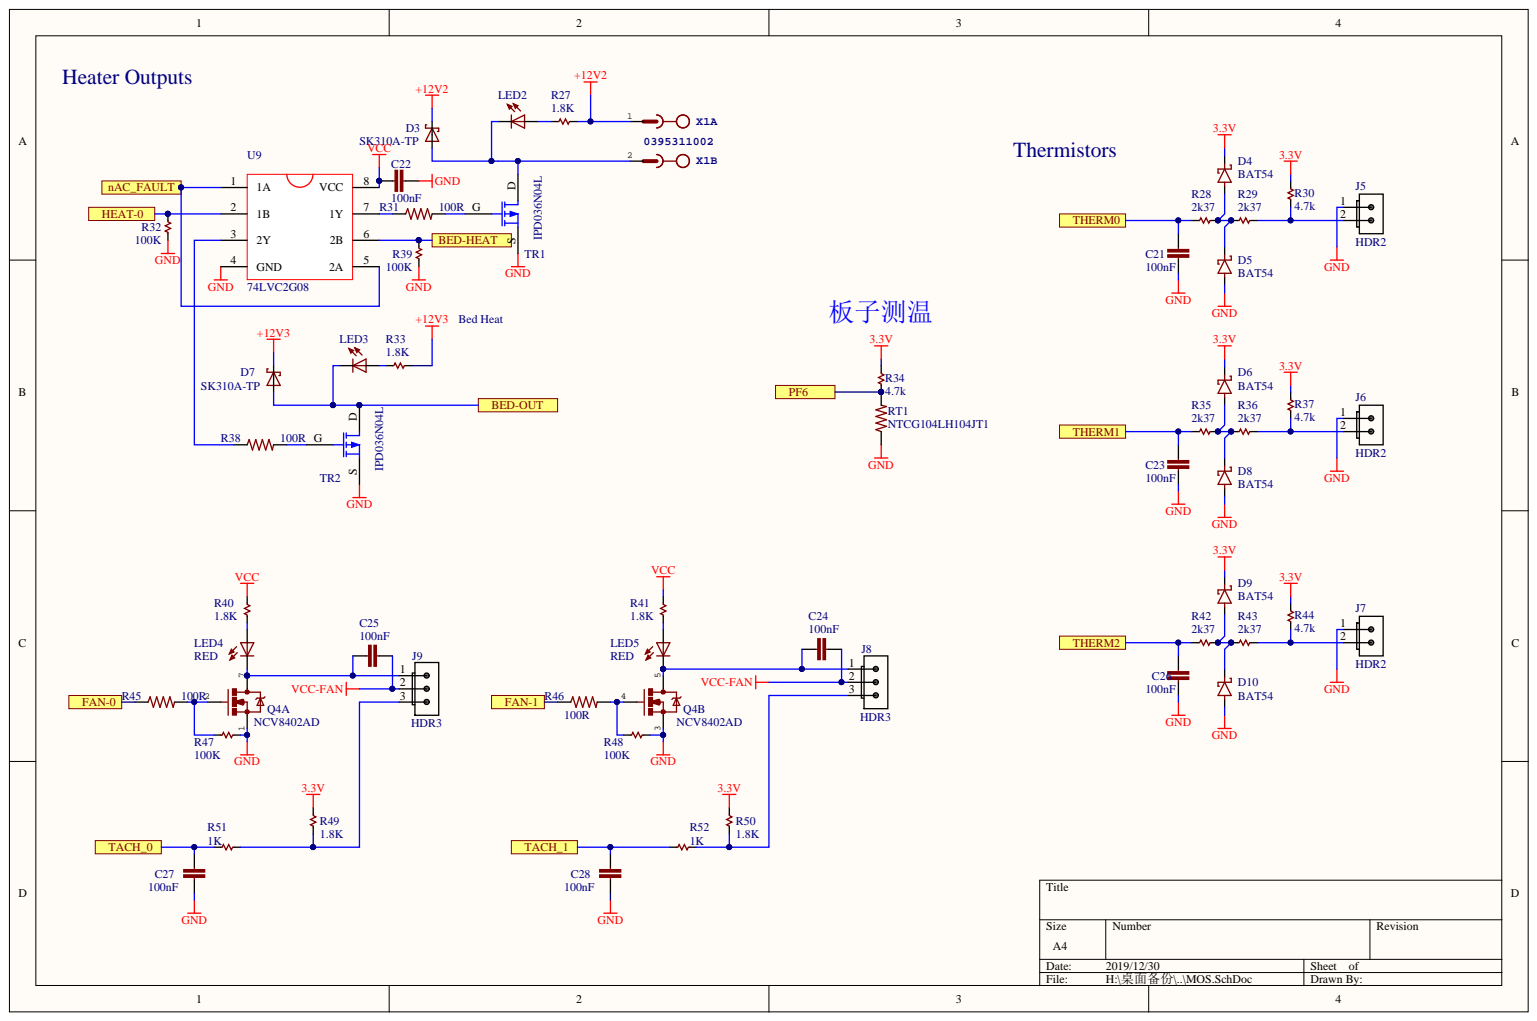
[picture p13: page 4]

A | A

## VCC

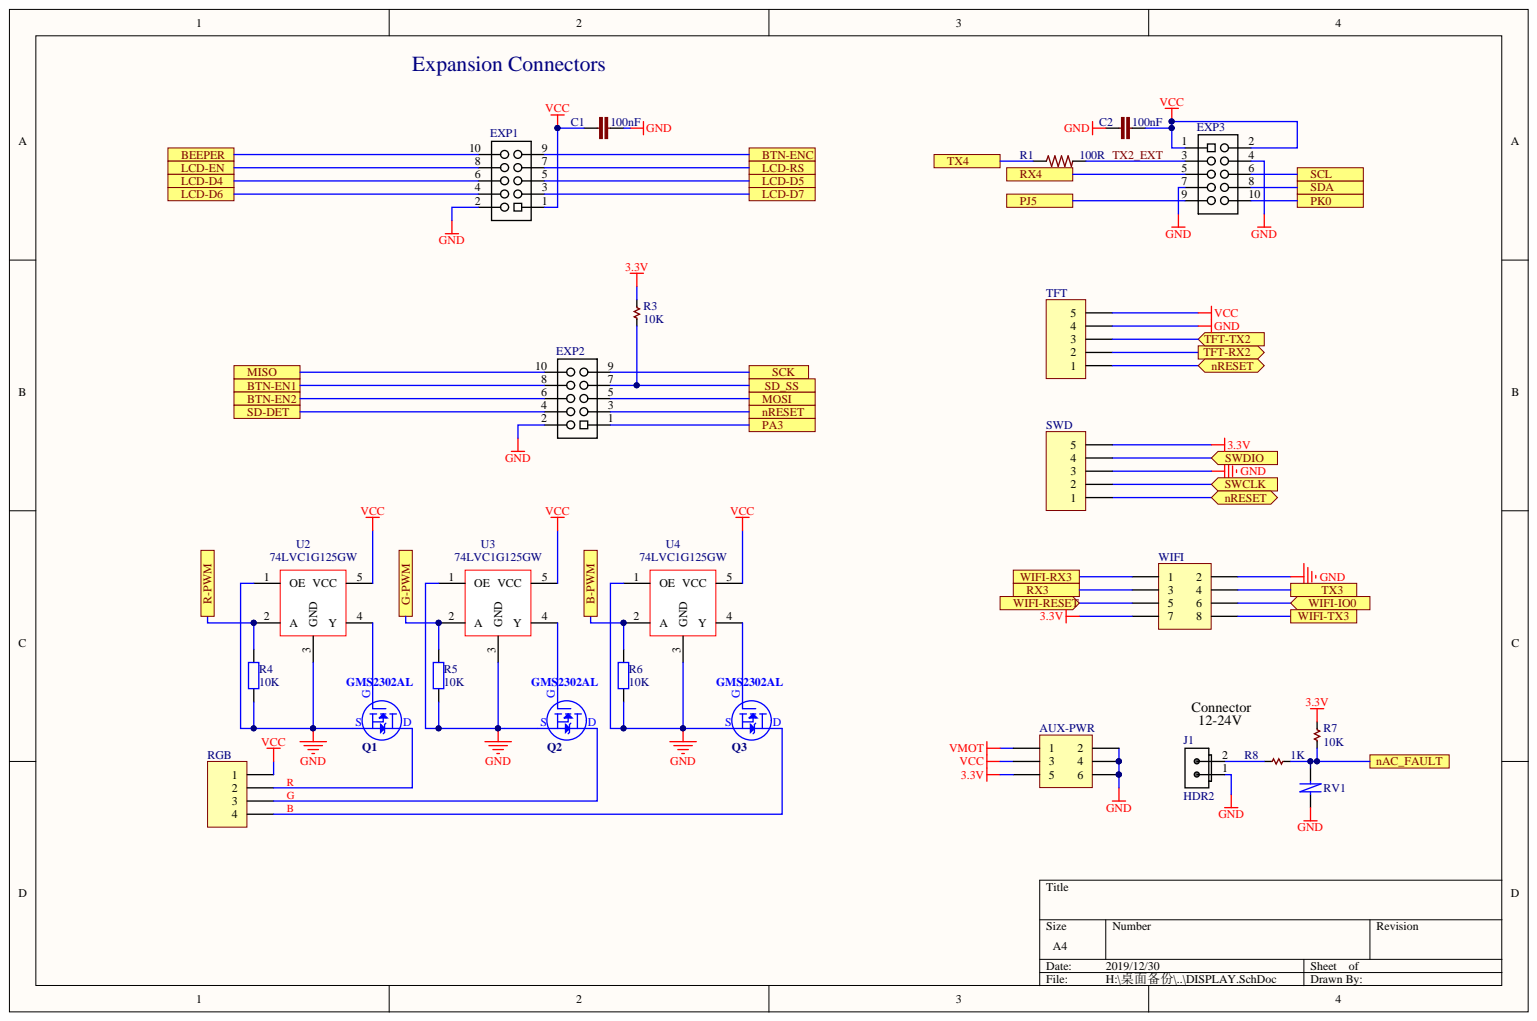
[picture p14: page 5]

11

22

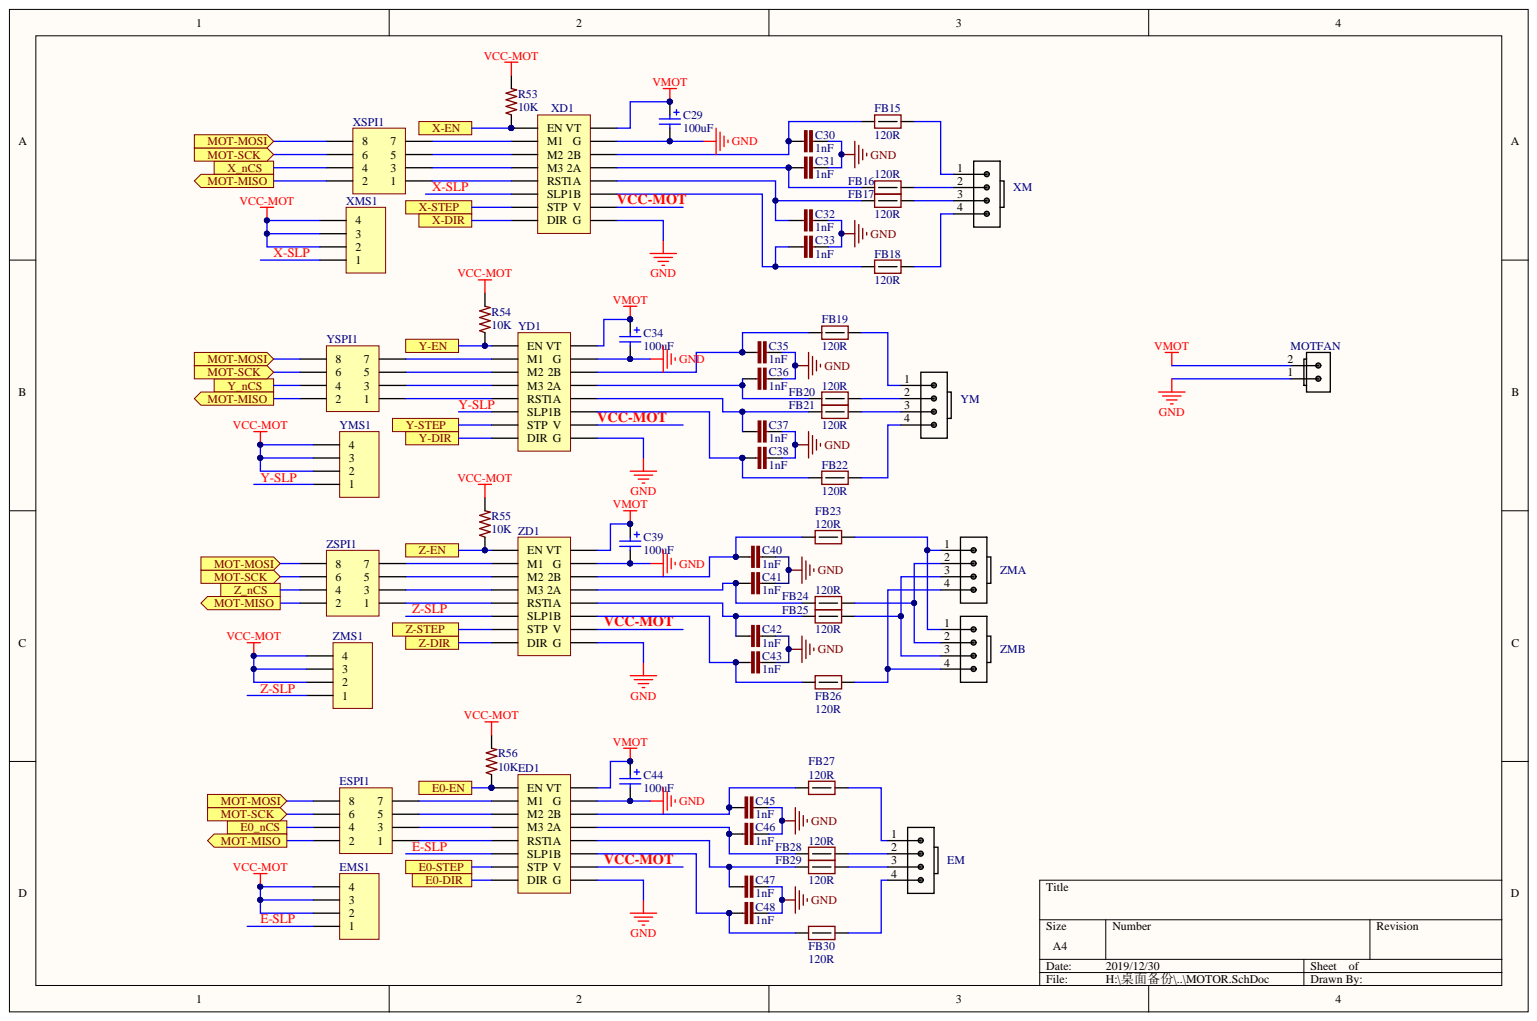
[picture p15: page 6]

# MCU

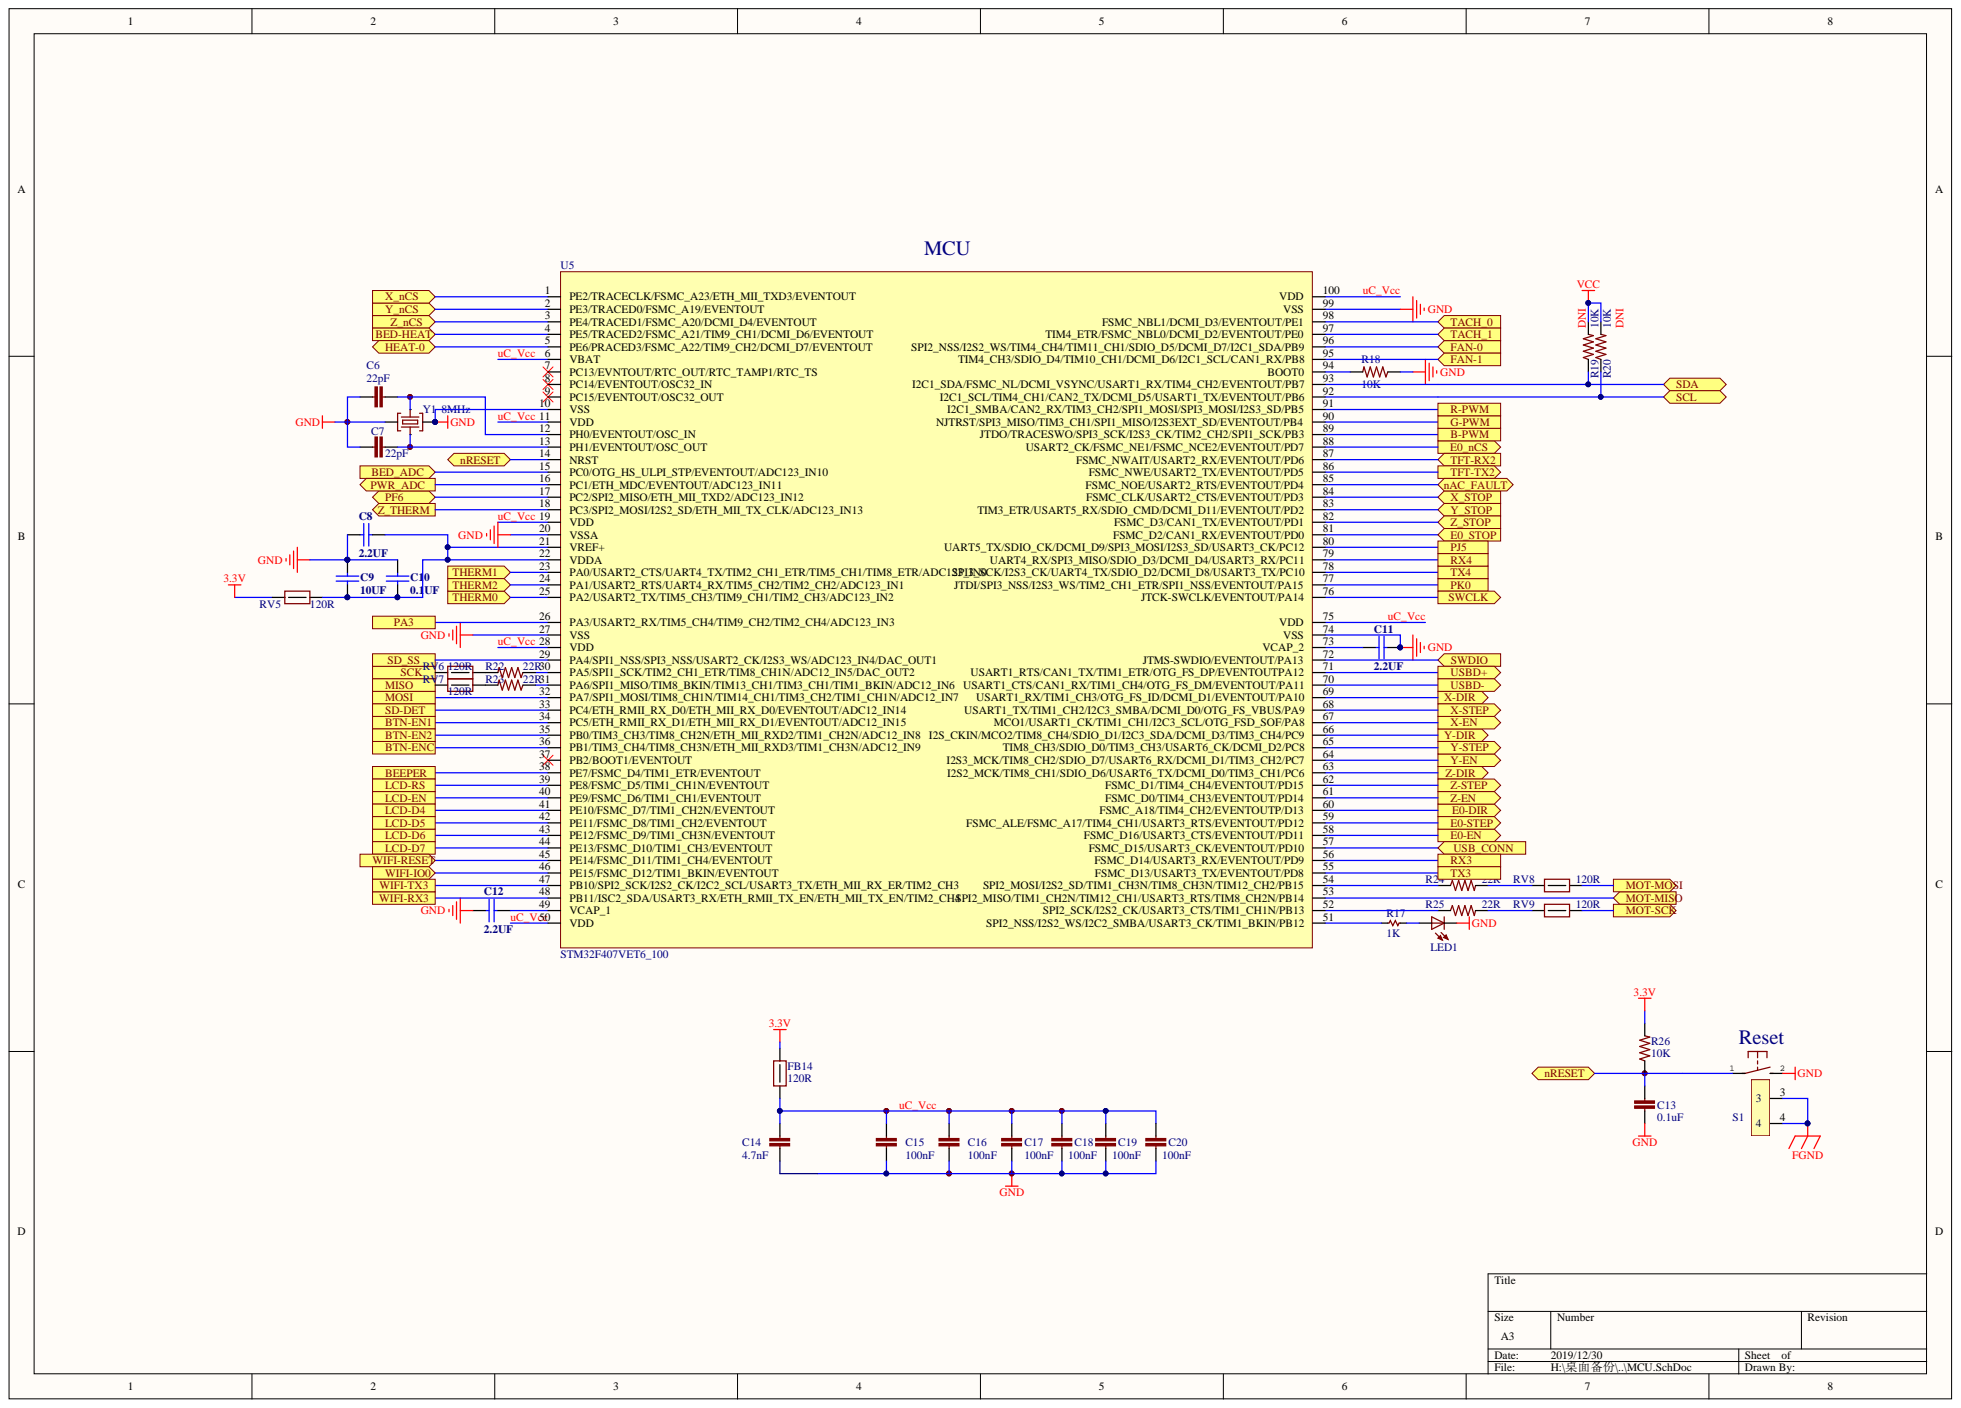
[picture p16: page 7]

LCD-D6 LCD-EN LCD-D4
